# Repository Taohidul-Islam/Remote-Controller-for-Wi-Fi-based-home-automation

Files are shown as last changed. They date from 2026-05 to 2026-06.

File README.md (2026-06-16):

9<h1>This is a Wi-Fi Based Remote Controller</h1>
<h2>The remote controller is specifically made for my previous project<a href="https://github.com/Taohidul-Islam/Wi-Fi-Based-Home-Automation"> Wi-Fi-Based-Home-Automation</a></h2>
<p>The remote controller has a thin form factor of 15mm. It uses a wesmos D1 mini as an MCU, a 3.7V Li-ion battery, TP4056 module(type-c) to charge the battery, and a TPS6123 module.<br>
It also does have a debug LED.</p>
<p>The keypad used in the remote is a membrane 4 by 4 matrix. Clicking specific button suck as numeric 1 to 8 gives specific http requests to a webserver hosted on the home automation. Then the server toggles respective switches from on to off or off to on. A, B, C, D and other keys are for extra functions such as display changer, reset buttons or led indicator toggler, firmware update requester for Home Automation etc. The remote controller is a accessory for the home automations device. </p>
<p>The remote can it's own update via OTA.
<h3>KeyMap</h3>
  <p>1---> Toggles Relay 1<br>
     2---> Toggles Relay 2<br>
     3---> Toggles Relay 3<br>
     4---> Toggles Relay 4<br>
     5---> Toggles Relay 5<br>
     6---> Toggles Relay 6<br>
     7---> Toggles Relay 7<br>
     8---> Toggles Relay 8<br>
     9---> Increase people count by one. <br>
     0---> Decrease people count by one. <br>
     A---> Changes display output and keeps the screen still<br>
     B---> Changes display output and keeps the screen switching<br>
     C---> Toggles LED indicator<br>
     D---> Toggles all relays at once.<br>
     *, 0, 9 simountaniously---> Resets Home Automation. <br>
     *, 0, 1 Simountaniously---> Request Home Automation to seek for updates. <br>
     #, 0, 1 Simountaniously---> Request the remote controller to seek for updates. <br>

  </p>
  
<p>The remote has a very compact form factor of about 7 by 7 by 2 cm. And it eradicates the direction problem we face with IR remotes.</p>





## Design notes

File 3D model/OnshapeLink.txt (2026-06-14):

https://cad.onshape.com/documents/6c715ea145059d6958eb1817/w/a85fbc1c2cc6ef3d389a7395/e/d93dee0acca715b593ab45ad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

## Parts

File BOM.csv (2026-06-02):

Sl. No. | Component Name | Component Model | Number of components per unit | Component Price Per Unit (BDT) | Component Price Per Unit (USD) | Required amount of components | Buying Unit | Buying Price(BDT) | Buying Price(USD) | Components Buying URL
1 | Micro Controller Board | ESP 8266 WeMos D1 Mini | 1 | 350 | 2.85 | 1 | 1 | 350 | 2.85 | https://store.roboticsbd.com/development-boards/2652-wemos-d1-mini-nodemcu-robotics-bangladesh.html
2 | Connector 1 | JST 2 Pin Male | 10 | 85 | 0.69 | 2 | 1 | 85 | 0.69 | https://www.daraz.com.bd/products/10-2-jst-xh-2-254mm-pcb-diy-i143574280-s1067884855.html?c=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
3 | Connector 2 | JST 2 Pin Female Cable | 3 | 105 | 0.85 | 2 | 1 | 105 | 0.85 | https://www.daraz.com.bd/products/3-2-f-o-2-254mm-jst-xh-27cm-diy-i145620356-s1071012613.html?c=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
4 | Connector 3 | JST 8 Pin Male | 2 | 66 | 0.54 | 1 | 1 | 66 | 0.54 | https://www.daraz.com.bd/products/2-8-jst-xh-8-254mm-pcb-diy-i141206726-s1064872419.html?c=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
5 | Resistor R1 | 1K Ohm | 0 | 0 | 0 | 1 | 0 | 0 | 0 | I already have them
6 | Resistor R2 | 100 Ohm | 0 | 0 | 0 | 1 | 0 | 0 | 0 | I already have them
7 | Transistor | NPN 2N222 | 0 | 0 | 0 | 1 | 0 | 0 | 0 | I already have them
8 | Switch | Push Switch | 10 | 96 | 0.78 | 1 | 1 | 96 | 0.78 | https://www.daraz.com.bd/products/2-30v-1a-10pcs-i145622836-s1071034187.html?c=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
9 | Charging Module | TP4056 Type C module | 1 | 64 | 0.52 | 1 | 1 | 64 | 0.52 | https://www.daraz.com.bd//products/i152828841-s1080964091.html?urlFlag=true
10 | Keypad | 4x4 Membrane Keypad | 1 | 124 | 1.01 | 1 | 1 | 124 | 1.01 | https://www.daraz.com.bd/products/44-keypad-keyboard-44-membrane-switches-matrix-keypad-16-key-thin-flexible-with-cables-connector-keypad-44-for-arduino-i3281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
11 | Voltage Booster | TPS6123 Module | 1 | 490 | 3.99 | 1 | 1 | 490 | 3.99 | https://store.roboticsbd.com/power-module-adapter/4091-tps61023-5v-1a-boost-regulator-module-robotics-bangladesh.html
12 | Battery | 3.7V Li-Po Battery | 1 | 426 | 3.47 | 1 | 1 | 426 | 3.47 | https://www.daraz.com.bd/products/1200mah-1s-25c-37v-lipo-37v-1200mah-25c-1s-1200mah-66x31x8mm-1200mah-jst-51005-2pin-i143078841-s1067208206.html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
13 | PCB | Custom PCB by JLC PCB | 5 | 245.82 | 2 | 1 | 1 | 245.82 | 2 | https://cart.jlcpcb.com/shopcart/cartEdit/?id=44330706b19b4ec3a25f29b8f853687d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
14 | Tape | Double Side Foam Tape | 1 | 92 | 0.75 | 1 | 1 | 92 | 0.75 | https://www.daraz.com.bd/products/25mm-1-25mm-1-i147794127-s1073552775.html?c=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
15 | Shipping 1 | Daraz BD Shipping | 1 | 90 | 0.73 | 1 | 1 | 90 | 0.73
16 | Shipping 2 | Robotics BD Shipping | 1 | 55 | 0.45 | 1 | 1 | 55 | 0.45
17 | Shipping 3 | JLC PCB E-Post Shipping | 1 | 1000.49 | 8.14 | 1 | 1 | 1000.49 | 8.14
18
19
20 | Total |  |  | 3289.31 | 26.77 |  |  | 3289.31 | 26.77
21
22
23
24
25
26
27
28
29
30
31
32
33
34
35
36

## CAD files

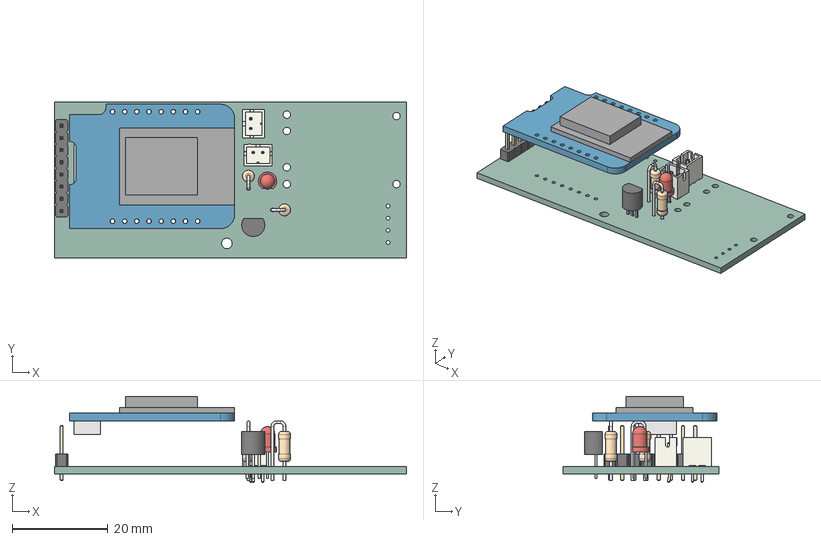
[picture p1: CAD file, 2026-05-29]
3D model/remotecircuit.step
73.5 x 32.5 x 18.0 mm
TO-92_Inline_Narrow
wemos_d1_mini_light
R_Axial_DIN0207_L63mm_D25mm_P254mm_Vertical x 2
LED_D3.0mm
JST_B2B_PH_K x 2
PinHeader_1x08_P254mm_Vertical
Wi-Fi Home Automation remote_PCB

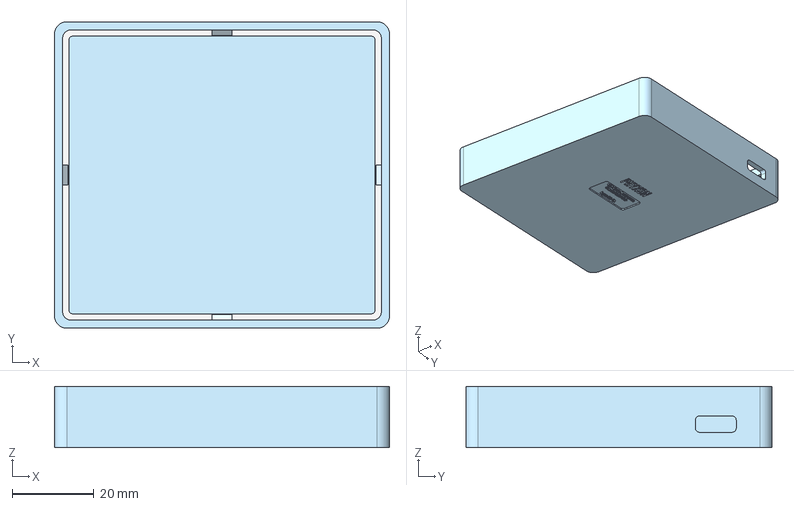
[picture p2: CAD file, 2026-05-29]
3D model/Home Automation Remote Case.step
82.0 x 75.0 x 15.0 mm
joint x 4
shelf

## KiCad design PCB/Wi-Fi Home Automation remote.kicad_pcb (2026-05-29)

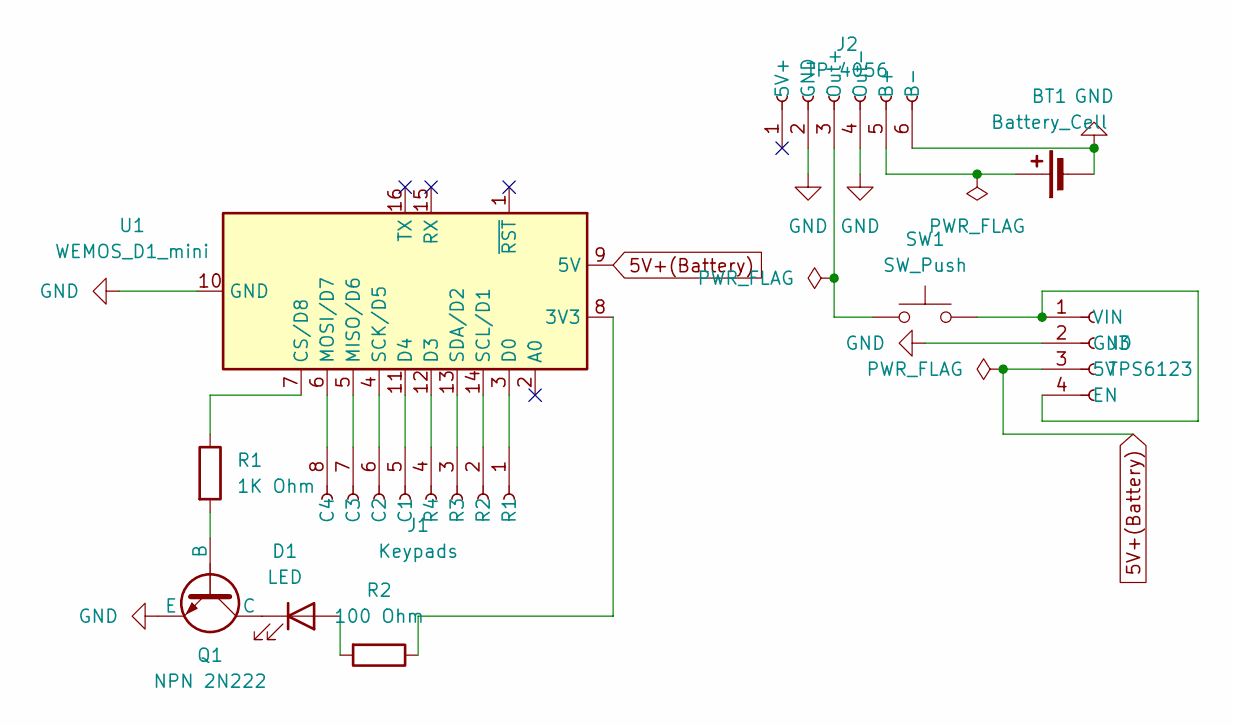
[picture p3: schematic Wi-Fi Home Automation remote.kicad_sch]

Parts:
BT1: Battery_Cell; JST_PH_B2B-PH-K_1x02_P2.00mm_Vertical
D1: LED; LED_D3.0mm
J1: Keypads; PinHeader_1x08_P2.54mm_Vertical
J2: TP 4056; TP4056-18650
J3: TPS6123; TPS61023 Module
Q1: NPN 2N222; TO-92_Inline
R1: 1K Ohm; R_Axial_DIN0207_L6.3mm_D2.5mm_P2.54mm_Vertical
R2: 100 Ohm; R_Axial_DIN0207_L6.3mm_D2.5mm_P2.54mm_Vertical
SW1: SW_Push; JST_PH_B2B-PH-K_1x02_P2.00mm_Vertical
U1: WEMOS_D1_mini; WEMOS_D1_mini_light

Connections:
5V+(Battery): J3.3 (5V), U1.9 (5V)
GND: BT1.2 (-), J2.2 (GND), J2.4 (Out-), J2.6 (B-), J3.2 (GND), Q1.3 (E), U1.10 (GND)
unnamed: BT1.1 (+), J2.5 (B+)
unnamed: D1.2 (A), R2.2
unnamed: D1.1 (K), Q1.1 (C)
unnamed: J1.5 (C1), U1.11 (D4)
unnamed: J1.6 (C2), U1.4 (SCK/D5)
unnamed: J1.7 (C3), U1.5 (MISO/D6)
unnamed: J1.8 (C4), U1.6 (MOSI/D7)
unnamed: J1.1 (R1), U1.3 (D0)
unnamed: J1.2 (R2), U1.14 (SCL/D1)
unnamed: J1.3 (R3), U1.13 (SDA/D2)
unnamed: J1.4 (R4), U1.12 (D3)
unnamed: J2.3 (Out+), SW1.1
unnamed: J3.1 (VIN), J3.4 (EN), SW1.2
unnamed: Q1.2 (B), R1.2
unnamed: R2.1, U1.8 (3V3)
unnamed: R1.1, U1.7 (CS/D8)

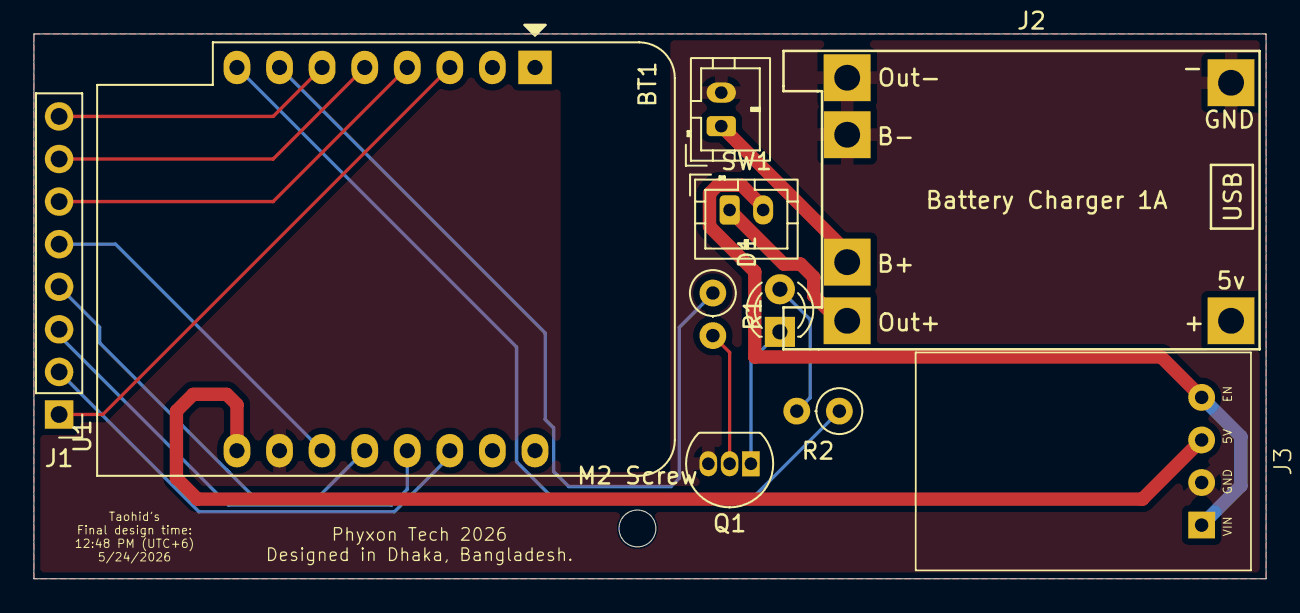
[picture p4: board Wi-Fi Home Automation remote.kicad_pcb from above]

Board: 2 copper layers, 73.5 x 32.5 mm, 11 parts (0 on the bottom side), 18 nets.

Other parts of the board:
M2 Screw: MountingHole_2.2mm_M2

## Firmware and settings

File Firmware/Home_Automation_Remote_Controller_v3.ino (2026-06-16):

/*
 * ============================================================
 *   Phyxon Remote Controller Firmware v3.0
 *   by Taohid | Phyxon Tech
 *   Hardware: Wemos D1 Mini (ESP8266)
 *   Target: Phyxon Home Automation v2.x (192.168.0.200)
 * ============================================================
 *
 * Changes in v3.0:
 *   - 1-8: toggle relays 1-8
 *   - 9: increase people count
 *   - 0: decrease people count
 *   - A: cycle OLED screen, fix it (no auto-switch after)
 *   - B: cycle OLED screen, keep auto-switch running
 *   - C: toggle LED indicator on main board
 *   - D: all ON if any off, else all OFF
 *   - * + 0 + 9 TRUE simultaneously: factory reset main board
 *   - * + 0 + 1 TRUE simultaneously: OTA update main board
 *   - # + 0 + 1 TRUE simultaneously: OTA update this remote
 *
 * Combo Detection:
 *   Full keypad matrix scanned every loop to detect ALL keys held at once.
 *   Combo fires when all 3 required keys are down simultaneously and then
 *   all released (fire-on-release to avoid accidental repeat).
 *   * 0 9 = factory reset main board
 *   * 0 1 = OTA update main board
 *   # 0 1 = OTA update this remote
 *
 * Pin Mapping:
 *   Debug LED  : D8 / GPIO15 (NPN transistor, active HIGH)
 *   Keypad Rows: D0/GPIO16=R1, D1/GPIO5=R2, D2/GPIO4=R3, D3/GPIO0=R4
 *   Keypad Cols: D4/GPIO2=C1, D5/GPIO14=C2, D6/GPIO12=C3, D7/GPIO13=C4
 *
 * Keypad Layout:
 *   [ 1 ][ 2 ][ 3 ][ A ]   R1
 *   [ 4 ][ 5 ][ 6 ][ B ]   R2
 *   [ 7 ][ 8 ][ 9 ][ C ]   R3
 *   [ * ][ 0 ][ # ][ D ]   R4
 *    C1   C2   C3   C4
 * ============================================================
 */

#include <ESP8266WiFi.h>
#include <ESP8266WebServer.h>
#include <ESP8266HTTPClient.h>
#include <ESP8266httpUpdate.h>
#include <EEPROM.h>
#include <DNSServer.h>

// ─── Pin Definitions ────────────────────────────────────────
#define LED_PIN   15   // D8 - debug LED via NPN (active HIGH)
#define ROW1      16   // D0 - no internal pull-up
#define ROW2       5   // D1
#define ROW3       4   // D2
#define ROW4       0   // D3 - boot pin, HIGH at boot
#define COL1       2   // D4 - boot pin, HIGH at boot
#define COL2      14   // D5
#define COL3      12   // D6
#define COL4      13   // D7

// ─── Network Config ─────────────────────────────────────────
const char*  AP_SSID            = "Phyxon Remote Controller";
IPAddress    AP_IP(192, 168, 5, 1);
IPAddress    AP_GATEWAY(192, 168, 5, 1);
IPAddress    AP_SUBNET(255, 255, 255, 0);
IPAddress    REMOTE_STATIC_IP(192, 168, 0, 150);
IPAddress    HOME_GATEWAY(192, 168, 0, 1);
IPAddress    HOME_SUBNET(255, 255, 255, 0);
IPAddress    HOME_DNS(192, 168, 0, 1);

const char*  HOME_AUTO_IP       = "192.168.0.200";
const int    HOME_AUTO_PORT     = 80;

// OTA servers
const char*  OTA_HOST_MAIN      = "103.92.206.122";
const int    OTA_PORT_MAIN      = 8080;   // main board OTA
const int    OTA_PORT_REMOTE    = 8282;   // remote OTA
const char*  REMOTE_FW_VERSION  = "3.0";

// ─── EEPROM ─────────────────────────────────────────────────
#define EEPROM_SIZE       160
#define EEPROM_MAGIC      0xAB
#define EEPROM_MAGIC_ADDR 0
#define EEPROM_SSID_ADDR  1
#define EEPROM_PASS_ADDR  65

// ─── State Machine ──────────────────────────────────────────
enum RemoteState { STATE_AP, STATE_CONNECTING, STATE_CONNECTED };
RemoteState currentState = STATE_AP;

ESP8266WebServer server(80);
DNSServer        dnsServer;

// ─── LED ────────────────────────────────────────────────────
unsigned long ledTimer     = 0;
int           ledBlinkStep = 0;
bool          ledState_    = false;
bool          feedbackActive = false;
int           feedbackCount  = 0;
unsigned long feedbackTimer  = 0;

void ledOn()  { digitalWrite(LED_PIN, HIGH); ledState_=true;  }
void ledOff() { digitalWrite(LED_PIN, LOW);  ledState_=false; }

void updateLED() {
  unsigned long now = millis();
  if(feedbackActive) {
    if(now-feedbackTimer >= 60) {
      feedbackTimer=now; ledState_=!ledState_;
      digitalWrite(LED_PIN, ledState_?HIGH:LOW);
      if(--feedbackCount<=0) {
        feedbackActive=false; ledOff();
        ledTimer=now; ledBlinkStep=0;
      }
    }
    return;
  }
  switch(currentState) {
    case STATE_AP: {
      unsigned long iv[]={80,80,80,760};
      if(now-ledTimer>=iv[ledBlinkStep]) {
        ledTimer=now; ledBlinkStep=(ledBlinkStep+1)%4;
        (ledBlinkStep==1||ledBlinkStep==3)?ledOff():ledOn();
      }
    } break;
    case STATE_CONNECTING: {
      unsigned long iv[]={100,900};
      if(now-ledTimer>=iv[ledBlinkStep]) {
        ledTimer=now; ledBlinkStep=(ledBlinkStep+1)%2;
        ledBlinkStep==0?ledOn():ledOff();
      }
    } break;
    case STATE_CONNECTED: ledOff(); break;
  }
}

void triggerFeedback(bool success) {
  feedbackCount  = success ? 4 : 2;
  feedbackActive = true;
  feedbackTimer  = millis()-61;
  ledState_      = false;
}

void rapidBlink(int times) {
  for(int i=0;i<times*2;i++) {
    digitalWrite(LED_PIN, i%2==0?HIGH:LOW);
    delay(80);
  }
  ledOff();
}

// ─── Keypad ─────────────────────────────────────────────────
const int ROWS=4, COLS=4;
int rowPins[ROWS]={ROW1,ROW2,ROW3,ROW4};
int colPins[COLS]={COL1,COL2,COL3,COL4};
const char keyMap[ROWS][COLS]={
  {'1','2','3','A'},
  {'4','5','6','B'},
  {'7','8','9','C'},
  {'*','0','#','D'}
};

// ─── Full Matrix Scan (all keys at once) ─────────────────────
// Returns a bitmask of all currently pressed keys.
// Bit index = r*COLS + c
uint16_t scanAllKeys() {
  uint16_t mask = 0;
  for(int r=0;r<ROWS;r++) {
    pinMode(rowPins[r],OUTPUT);
    digitalWrite(rowPins[r],LOW);
    delayMicroseconds(50);
    for(int c=0;c<COLS;c++) {
      if(digitalRead(colPins[c])==LOW)
        mask |= (1 << (r*COLS + c));
    }
    digitalWrite(rowPins[r],HIGH);
    pinMode(rowPins[r],INPUT);
  }
  return mask;
}

// Convert a key character to its bitmask bit position
int keyToBit(char k) {
  for(int r=0;r<ROWS;r++)
    for(int c=0;c<COLS;c++)
      if(keyMap[r][c]==k) return r*COLS+c;
  return -1;
}

bool keyInMask(uint16_t mask, char k) {
  int b=keyToBit(k);
  return (b>=0) && (mask & (1<<b));
}

// ─── Single Key Detection (debounced, one-shot) ──────────────
char     lastSingleKey   = 0;
uint16_t lastMask        = 0;

// Returns a single key on first press (edge detect), 0 otherwise.
// Only fires when exactly 1 key is held (ignores multi-key presses).
char getKey() {
  uint16_t mask = scanAllKeys();
  // Count pressed keys
  int count = 0;
  char foundKey = 0;
  for(int r=0;r<ROWS;r++)
    for(int c=0;c<COLS;c++)
      if(mask & (1<<(r*COLS+c))) { count++; foundKey=keyMap[r][c]; }

  if(count==1) {
    if(foundKey != lastSingleKey) {
      lastSingleKey = foundKey;
      lastMask = mask;
      return foundKey;
    }
  } else {
    lastSingleKey = 0;
  }
  lastMask = mask;
  return 0;
}

// ─── Simultaneous Combo Detection ────────────────────────────
// Combos fire when ALL required keys are held at the same time,
// then released. Fire-on-release prevents re-triggering.
//
//  1 = * + 0 + 9 → factory reset main board
//  2 = * + 0 + 1 → OTA update main board
//  3 = # + 0 + 1 → OTA update this remote

bool comboFired     = false;  // true while combo keys are held (already fired)
int  pendingCombo   = 0;      // which combo was detected

int checkSimultaneousCombo(uint16_t mask) {
  bool star  = keyInMask(mask,'*');
  bool hash  = keyInMask(mask,'#');
  bool zero  = keyInMask(mask,'0');
  bool one   = keyInMask(mask,'1');
  bool nine  = keyInMask(mask,'9');

  if(star && zero && nine)  return 1;  // * 0 9 → reset
  if(star && zero && one)   return 2;  // * 0 1 → HA OTA
  if(hash && zero && one)   return 3;  // # 0 1 → remote OTA
  return 0;
}

// Call every loop. Returns combo ID on release, 0 otherwise.
int updateCombo() {
  uint16_t mask = lastMask;  // reuse what getKey() already scanned
  int combo = checkSimultaneousCombo(mask);

  if(combo != 0) {
    if(!comboFired) {
      comboFired   = true;
      pendingCombo = combo;
    }
    return 0;  // still held, don't fire yet
  } else {
    // All combo keys released
    if(comboFired) {
      comboFired = false;
      int fired  = pendingCombo;
      pendingCombo = 0;
      return fired;  // fire on release
    }
  }
  return 0;
}

// ─── EEPROM ─────────────────────────────────────────────────
void eepromWriteString(int addr, const String& s, int maxLen) {
  int len=min((int)s.length(),maxLen-1);
  for(int i=0;i<len;i++) EEPROM.write(addr+i,s[i]);
  EEPROM.write(addr+len,0); EEPROM.commit();
}
String eepromReadString(int addr, int maxLen) {
  String r="";
  for(int i=0;i<maxLen;i++) {
    char c=(char)EEPROM.read(addr+i);
    if(c==0) break; r+=c;
  }
  return r;
}
bool loadCredentials(String& ssid, String& pass) {
  if(EEPROM.read(EEPROM_MAGIC_ADDR)!=EEPROM_MAGIC) return false;
  ssid=eepromReadString(EEPROM_SSID_ADDR,64);
  pass=eepromReadString(EEPROM_PASS_ADDR,64);
  return ssid.length()>0;
}
void saveCredentials(const String& ssid, const String& pass) {
  EEPROM.write(EEPROM_MAGIC_ADDR,EEPROM_MAGIC);
  eepromWriteString(EEPROM_SSID_ADDR,ssid,64);
  eepromWriteString(EEPROM_PASS_ADDR,pass,64);
}
void clearCredentials() {
  EEPROM.write(EEPROM_MAGIC_ADDR,0); EEPROM.commit();
}

// ─── HTTP Helpers ────────────────────────────────────────────
bool httpPost(const String& path) {
  if(WiFi.status()!=WL_CONNECTED) return false;
  WiFiClient client; HTTPClient http;
  http.begin(client,"http://"+String(HOME_AUTO_IP)+path);
  http.setTimeout(2000);
  int code=http.POST(""); http.end();
  Serial.println("[HTTP] POST "+path+" → "+String(code));
  return (code==200);
}

bool httpGet(const String& path, String& response) {
  if(WiFi.status()!=WL_CONNECTED) return false;
  WiFiClient client; HTTPClient http;
  http.begin(client,"http://"+String(HOME_AUTO_IP)+path);
  http.setTimeout(2000);
  int code=http.GET();
  if(code==200) response=http.getString();
  http.end();
  return (code==200);
}

// ─── Relay State Cache ───────────────────────────────────────
bool relayStates[8]  = {false};
bool statesFetched   = false;

void fetchStatus() {
  String resp;
  if(!httpGet("/status",resp)) return;
  int start=resp.indexOf("\"relays\":[");
  if(start<0) return;
  start+=10;
  for(int i=0;i<8;i++) {
    int t=resp.indexOf("true",start);
    int f=resp.indexOf("false",start);
    if(t<0&&f<0) break;
    bool isFalse=(f>=0&&(t<0||f<t));
    relayStates[i]=!isFalse;
    start=isFalse?f+5:t+4;
  }
  statesFetched=true;
  Serial.println("[STATUS] Relay states fetched");
}

// ─── OTA Update Main Board ───────────────────────────────────
void otaUpdateMainBoard() {
  Serial.println("[OTA] Triggering main board update...");
  rapidBlink(3);
  bool ok=httpPost("/doupdate");
  triggerFeedback(ok);
  Serial.println("[OTA] Main board update request: "+(String)(ok?"OK":"FAIL"));
}

// ─── OTA Update This Remote ──────────────────────────────────
void otaUpdateRemote() {
  Serial.println("[OTA] Updating remote firmware...");
  rapidBlink(5);
  String url="http://"+String(OTA_HOST_MAIN)+":"+String(OTA_PORT_REMOTE)+"/firmware.bin";
  t_httpUpdate_return ret=ESPhttpUpdate.update(url);
  switch(ret) {
    case HTTP_UPDATE_FAILED:
      Serial.println("[OTA] Failed: "+ESPhttpUpdate.getLastErrorString());
      rapidBlink(2); break;
    case HTTP_UPDATE_NO_UPDATES:
      Serial.println("[OTA] No updates"); break;
    case HTTP_UPDATE_OK:
      Serial.println("[OTA] Done, rebooting..."); break;
  }
}

// ─── Key Actions ────────────────────────────────────────────
void toggleRelay(int idx) {
  bool ok=httpPost("/toggle?relay="+String(idx));
  if(ok) relayStates[idx]=!relayStates[idx];
  triggerFeedback(ok);
}

int getPeopleCount() {
  String resp;
  if(!httpGet("/status",resp)) return -1;
  int pi=resp.indexOf("\"people\":");
  if(pi<0) return -1;
  return resp.substring(pi+9,pi+12).toInt();
}

void handleKey(char k) {
  Serial.println("[KEY] "+String(k));
  if(currentState!=STATE_CONNECTED) return;

  switch(k) {
    // Relays 1-8
    case '1': toggleRelay(0); break;
    case '2': toggleRelay(1); break;
    case '3': toggleRelay(2); break;
    case '4': toggleRelay(3); break;
    case '5': toggleRelay(4); break;
    case '6': toggleRelay(5); break;
    case '7': toggleRelay(6); break;
    case '8': toggleRelay(7); break;

    // 9 = increase people count
    case '9': {
      int c=getPeopleCount();
      if(c>=0) {
        bool ok=httpPost("/setpeople?count="+String(c+1));
        triggerFeedback(ok);
      }
      break;
    }

    // 0 = decrease people count
    case '0': {
      int c=getPeopleCount();
      if(c>0) {
        bool ok=httpPost("/setpeople?count="+String(c-1));
        triggerFeedback(ok);
      }
      break;
    }

    // A = cycle OLED screen and fix it (no auto-switch)
    case 'A': {
      bool ok=httpPost("/olednext?fix=1");
      triggerFeedback(ok);
      break;
    }

    // B = cycle OLED screen, keep auto-switch
    case 'B': {
      bool ok=httpPost("/olednext?fix=0");
      triggerFeedback(ok);
      break;
    }

    // C = toggle LED indicator
    case 'C': {
      bool ok=httpPost("/toggleled");
      triggerFeedback(ok);
      break;
    }

    // D = all ON if any off, else all OFF
    case 'D': {
      if(!statesFetched) fetchStatus();
      bool anyOff=false;
      for(int i=0;i<8;i++) if(!relayStates[i]){anyOff=true;break;}
      bool ok=httpPost(anyOff?"/allrelays?state=1":"/allrelays?state=0");
      if(ok) for(int i=0;i<8;i++) relayStates[i]=anyOff;
      triggerFeedback(ok);
      break;
    }

    // *, #, 1, 0, 9 — part of simultaneous combos, no standalone action
    case '*': break;
    case '#': break;

    default: break;
  }
}

// ─── Web Server Pages ────────────────────────────────────────
static const char CONFIG_PAGE[] PROGMEM = R"rawhtml(
<!DOCTYPE html><html><head>
<meta name='viewport' content='width=device-width,initial-scale=1'>
<meta charset='UTF-8'><title>Phyxon Remote Setup</title>
<style>
*{box-sizing:border-box;margin:0;padding:0}
body{font-family:'Segoe UI',sans-serif;background:#1a1a2e;color:#e0e0e0;
     display:flex;align-items:center;justify-content:center;min-height:100vh}
.card{background:#16213e;border-radius:12px;padding:30px;text-align:center;max-width:360px;width:90%}
h2{color:#4ade80;margin-bottom:8px;font-size:1.3rem}
p{color:#aaa;font-size:.85rem;margin-bottom:20px}
input{width:100%;padding:10px;border-radius:8px;border:1px solid #2a2a4a;
      background:#0f3460;color:#e0e0e0;font-size:.9rem;margin-bottom:12px}
button{width:100%;padding:12px;border:none;border-radius:8px;background:#4ade80;
       color:#111;font-weight:700;font-size:.95rem;cursor:pointer}
</style></head><body>
<div class='card'>
  <h2>Phyxon Remote v3.0</h2>
  <p>Enter your home WiFi credentials to connect</p>
  <form action='/savewifi' method='post'>
    <input name='ssid' placeholder='WiFi SSID' required>
    <input name='password' type='password' placeholder='Password'>
    <button type='submit'>Connect</button>
  </form>
</div></body></html>
)rawhtml";

static const char SAVED_PAGE[] PROGMEM = R"rawhtml(
<!DOCTYPE html><html><head>
<meta name='viewport' content='width=device-width,initial-scale=1'>
<title>Saved</title>
<style>
body{font-family:'Segoe UI',sans-serif;background:#1a1a2e;color:#e0e0e0;
     display:flex;align-items:center;justify-content:center;min-height:100vh}
.card{background:#16213e;border-radius:12px;padding:30px;text-align:center;max-width:360px;width:90%}
h2{color:#4ade80;margin-bottom:12px}p{color:#aaa;font-size:.85rem;line-height:1.6}
</style></head><body>
<div class='card'>
  <h2>&#x2714; Saved!</h2>
  <p>Credentials saved.<br>Restarting and connecting...<br><br>
  Remote will be at <strong>192.168.0.150</strong></p>
</div></body></html>
)rawhtml";

void handleRoot()    { server.send_P(200,"text/html",CONFIG_PAGE); }
void handleCaptive() { server.sendHeader("Location",String("http://")+AP_IP.toString()+"/",true); server.send(302,"text/plain",""); }
void handleSaveWifi(){
  if(server.hasArg("ssid")&&server.arg("ssid").length()>0){
    saveCredentials(server.arg("ssid"),server.arg("password"));
    server.send_P(200,"text/html",SAVED_PAGE);
    delay(2000); ESP.restart();
  } else { server.sendHeader("Location","/",true); server.send(302,"text/plain",""); }
}

// ─── AP Mode ────────────────────────────────────────────────
void startAPMode() {
  currentState=STATE_AP; ledBlinkStep=0; ledTimer=millis();
  WiFi.disconnect(true); delay(100);
  WiFi.mode(WIFI_AP);
  WiFi.softAPConfig(AP_IP,AP_GATEWAY,AP_SUBNET);
  WiFi.softAP(AP_SSID);
  dnsServer.start(53,"*",AP_IP);
  server.on("/",HTTP_GET,handleRoot);
  server.on("/savewifi",HTTP_POST,handleSaveWifi);
  server.onNotFound(handleCaptive);
  server.begin();
  Serial.println("[AP] "+String(AP_SSID));
}

// ─── WiFi Connect ────────────────────────────────────────────
bool connectToHomeWifi(const String& ssid, const String& pass) {
  currentState=STATE_CONNECTING; ledBlinkStep=0; ledTimer=millis();
  server.stop(); dnsServer.stop();
  WiFi.mode(WIFI_STA);
  WiFi.config(REMOTE_STATIC_IP,HOME_GATEWAY,HOME_SUBNET,HOME_DNS);
  WiFi.begin(ssid.c_str(),pass.c_str());
  Serial.print("[WiFi] Connecting to "+ssid);
  unsigned long start=millis();
  while(WiFi.status()!=WL_CONNECTED) {
    updateLED(); delay(10);
    if(millis()-start>15000){ Serial.println("\n[WiFi] Timeout"); return false; }
  }
  Serial.println("\n[WiFi] Connected: "+WiFi.localIP().toString());
  currentState=STATE_CONNECTED; ledOff();
  delay(500); fetchStatus();
  return true;
}

// ─── Setup ───────────────────────────────────────────────────
void setup() {
  Serial.begin(115200); delay(200);
  Serial.println("\n=== Phyxon Remote v3.0 ===");
  EEPROM.begin(EEPROM_SIZE);
  pinMode(LED_PIN,OUTPUT); ledOff();
  pinMode(COL1,INPUT_PULLUP); pinMode(COL2,INPUT_PULLUP);
  pinMode(COL3,INPUT_PULLUP); pinMode(COL4,INPUT_PULLUP);
  pinMode(ROW1,INPUT); pinMode(ROW2,INPUT);
  pinMode(ROW3,INPUT); pinMode(ROW4,INPUT);
  String savedSSID,savedPass;
  if(loadCredentials(savedSSID,savedPass)){
    Serial.println("[EEPROM] Found: "+savedSSID);
    if(!connectToHomeWifi(savedSSID,savedPass)){
      Serial.println("[WiFi] Failed, AP mode");
      startAPMode();
    }
  } else {
    Serial.println("[EEPROM] No creds, AP mode");
    startAPMode();
  }
}

// ─── Loop ────────────────────────────────────────────────────
void loop() {
  updateLED();
  if(currentState==STATE_AP){
    dnsServer.processNextRequest();
    server.handleClient();
  }

  // Single key (only fires when exactly 1 key held — also updates lastMask)
  char k = getKey();

  // Simultaneous combo check (uses lastMask populated by getKey)
  int combo = updateCombo();
  if(combo != 0) {
    // Suppress any single-key action when a combo fires
    k = 0;
    switch(combo) {
      case 1:
        // * + 0 + 9 → factory reset main board
        Serial.println("[COMBO] * 0 9 → Factory reset main board");
        rapidBlink(5);
        httpPost("/factoryreset");
        delay(500);
        break;
      case 2:
        // * + 0 + 1 → OTA update main board
        Serial.println("[COMBO] * 0 1 → OTA update main board");
        otaUpdateMainBoard();
        break;
      case 3:
        // # + 0 + 1 → OTA update this remote
        Serial.println("[COMBO] # 0 1 → OTA update remote");
        otaUpdateRemote();
        break;
    }
  }

  if(k != 0) handleKey(k);

  yield();
}

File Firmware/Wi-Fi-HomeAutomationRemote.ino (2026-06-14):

/*
 * Home Automation Remote Controller Firmware
 * Hardware: Wemos D1 Mini (ESP8266)
 * Target: Wi-Fi Based Home Automation (192.168.0.200)
 *
 * Pin Mapping:
 *   Debug LED  : D8 / GPIO15 (NPN transistor, active HIGH)
 *   Keypad Rows: D0/GPIO16=R1, D1/GPIO5=R2, D2/GPIO4=R3, D3/GPIO0=R4
 *   Keypad Cols: D4/GPIO2=C1, D5/GPIO14=C2, D6/GPIO12=C3, D7/GPIO13=C4
 *
 * Keypad Layout:
 *   [ 1 ][ 2 ][ 3 ][ A ]   R1
 *   [ 4 ][ 5 ][ 6 ][ B ]   R2
 *   [ 7 ][ 8 ][ 9 ][ C ]   R3
 *   [ * ][ 0 ][ # ][ D ]   R4
 *    C1   C2   C3   C4
 */

#include <ESP8266WiFi.h>
#include <ESP8266WebServer.h>
#include <ESP8266HTTPClient.h>
#include <EEPROM.h>
#include <DNSServer.h>

// ─── Pin Definitions ───────────────────────────────────────────────────────
#define LED_PIN     15   // D8 - debug LED via NPN transistor (active HIGH)

// Keypad rows (driven LOW one at a time to scan)
#define ROW1        16   // D0 - no internal pull-up, external needed
#define ROW2         5   // D1
#define ROW3         4   // D2
#define ROW4         0   // D3 - boot pin, must be HIGH at boot

// Keypad columns (read with internal pull-ups)
#define COL1         2   // D4 - boot pin, must be HIGH at boot
#define COL2        14   // D5
#define COL3        12   // D6
#define COL4        13   // D7

// ─── Network Config ────────────────────────────────────────────────────────
const char*   AP_SSID       = "Home-Auto Remote Controller";
const char*   AP_PASSWORD   = "";                    // Open network
IPAddress     AP_IP(192, 168, 5, 1);
IPAddress     AP_GATEWAY(192, 168, 5, 1);
IPAddress     AP_SUBNET(255, 255, 255, 0);

IPAddress     REMOTE_STATIC_IP(192, 168, 0, 150);   // Remote's static IP on home WiFi
IPAddress     HOME_GATEWAY(192, 168, 0, 1);
IPAddress     HOME_SUBNET(255, 255, 255, 0);
IPAddress     HOME_DNS(192, 168, 0, 1);

const char*   HOME_AUTO_IP  = "192.168.0.200";       // Main automation board IP
const int     HOME_AUTO_PORT = 80;

// ─── EEPROM Layout ─────────────────────────────────────────────────────────
#define EEPROM_SIZE         160
#define EEPROM_MAGIC        0xAB
#define EEPROM_MAGIC_ADDR   0
#define EEPROM_SSID_ADDR    1    // up to 64 bytes
#define EEPROM_PASS_ADDR    65   // up to 64 bytes

// ─── State Machine ─────────────────────────────────────────────────────────
enum RemoteState {
  STATE_AP,           // Hosting config AP, waiting for credentials
  STATE_CONNECTING,   // Trying to join home WiFi
  STATE_CONNECTED     // Connected, controlling home automation
};

RemoteState currentState = STATE_AP;

// ─── LED Blink Patterns ────────────────────────────────────────────────────
// AP mode      : double-blink every 1s  (on 80ms, off 80ms, on 80ms, off ~760ms)
// Connecting   : single blink every 1s  (on 100ms, off 900ms)
// Connected    : LED OFF
// Toggle ON    : two fast blinks         (on 60ms off 60ms x2)
// Toggle OFF   : one fast blink          (on 60ms off 60ms x1)

unsigned long ledTimer       = 0;
int           ledBlinkStep   = 0;
bool          ledState       = false;

// For transient feedback blinks (toggle on/off)
bool          feedbackActive = false;
int           feedbackCount  = 0;   // total half-cycles remaining
unsigned long feedbackTimer  = 0;

void ledOn()  { digitalWrite(LED_PIN, HIGH); ledState = true;  }
void ledOff() { digitalWrite(LED_PIN, LOW);  ledState = false; }

// Call every loop tick — handles all LED patterns non-blocking
void updateLED() {
  unsigned long now = millis();

  // Transient feedback blinks take priority
  if (feedbackActive) {
    if (now - feedbackTimer >= 60) {
      feedbackTimer = now;
      ledState = !ledState;
      digitalWrite(LED_PIN, ledState ? HIGH : LOW);
      feedbackCount--;
      if (feedbackCount <= 0) {
        feedbackActive = false;
        ledOff();
        ledTimer = now;     // reset pattern timer
        ledBlinkStep = 0;
      }
    }
    return;
  }

  switch (currentState) {

    case STATE_AP:
      // Double-blink pattern: ON-OFF-ON-OFF ... period ~1000ms
      // Steps: 0=on(80ms) 1=off(80ms) 2=on(80ms) 3=off(760ms)
      {
        unsigned long intervals[] = {80, 80, 80, 760};
        if (now - ledTimer >= intervals[ledBlinkStep]) {
          ledTimer = now;
          ledBlinkStep = (ledBlinkStep + 1) % 4;
          // Steps 0 and 2 are ON, 1 and 3 are OFF
          (ledBlinkStep == 1 || ledBlinkStep == 3) ? ledOff() : ledOn();
        }
      }
      break;

    case STATE_CONNECTING:
      // Single blink: ON 100ms, OFF 900ms
      {
        unsigned long intervals[] = {100, 900};
        if (now - ledTimer >= intervals[ledBlinkStep]) {
          ledTimer = now;
          ledBlinkStep = (ledBlinkStep + 1) % 2;
          ledBlinkStep == 0 ? ledOn() : ledOff();
        }
      }
      break;

    case STATE_CONNECTED:
      ledOff();
      break;
  }
}

// Trigger transient feedback (toggleOn=true → 2 blinks, false → 1 blink)
void triggerFeedback(bool toggleOn) {
  feedbackCount  = toggleOn ? 4 : 2;  // each blink = 2 half-cycles
  feedbackActive = true;
  feedbackTimer  = millis() - 61;     // fire immediately
  ledState       = false;
}

// ─── Keypad ────────────────────────────────────────────────────────────────
const int ROWS = 4;
const int COLS = 4;

int rowPins[ROWS] = {ROW1, ROW2, ROW3, ROW4};
int colPins[COLS] = {COL1, COL2, COL3, COL4};

// Key map matching physical layout
const char keyMap[ROWS][COLS] = {
  {'1', '2', '3', 'A'},
  {'4', '5', '6', 'B'},
  {'7', '8', '9', 'C'},
  {'*', '0', '#', 'D'}
};

char lastKey        = 0;
unsigned long keyPressTime = 0;
#define KEY_DEBOUNCE_MS  50
#define KEY_HOLD_IGNORE_MS 300   // ignore held keys

// Returns pressed key char or 0 if none
char scanKeypad() {
  for (int r = 0; r < ROWS; r++) {
    // Drive this row LOW
    pinMode(rowPins[r], OUTPUT);
    digitalWrite(rowPins[r], LOW);

    for (int c = 0; c < COLS; c++) {
      if (digitalRead(colPins[c]) == LOW) {
        // Key at [r][c] is pressed
        // Release row before returning
        digitalWrite(rowPins[r], HIGH);
        pinMode(rowPins[r], INPUT);
        return keyMap[r][c];
      }
    }

    // Release row
    digitalWrite(rowPins[r], HIGH);
    pinMode(rowPins[r], INPUT);
  }
  return 0;
}

// Returns a key only on the rising edge (press moment), not while held
char getKey() {
  char k = scanKeypad();
  unsigned long now = millis();

  if (k != 0) {
    if (k != lastKey) {
      lastKey = k;
      keyPressTime = now;
      return k;   // fresh press
    }
    // Same key still held — ignore
    return 0;
  } else {
    lastKey = 0;
    return 0;
  }
}

// ─── Reset Sequence Detection ──────────────────────────────────────────────
// * 0 # D pressed in sequence within MAX_SEQ_GAP_MS each
const char RESET_SEQ[]       = {'*', '0', '#', 'D'};
const int  RESET_SEQ_LEN     = 4;
const unsigned long MAX_SEQ_GAP_MS = 2000;

int           resetSeqIndex  = 0;
unsigned long resetSeqTimer  = 0;
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
